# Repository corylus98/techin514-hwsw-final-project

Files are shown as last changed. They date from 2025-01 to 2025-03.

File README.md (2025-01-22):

# Final Project - Hardware/Software Lab

## Focus Track
The product is a desktop companion device designed to enhance productivity and well-being while working. It sits beside the user's computer and uses sensors to monitor typing patterns and screen time. By analyzing typing speed and consistency, it identifies whether the user is focused on productive tasks or engaging in non-work-related activities. The device features:
- Focus Level Indicator: A needle-style display that reflects the user's focus level based on typing behavior, encouraging sustained productivity.
- Break Reminder System: An LED light that gently alerts the user when they've been at their screen for too long, promoting healthier work habits through regular breaks.

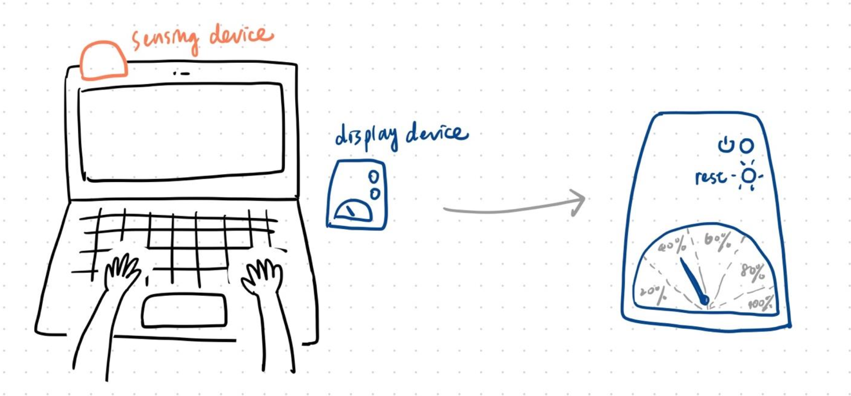
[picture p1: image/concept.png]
Imgae showing the scenario and concept of the idea.


## Sensor Device
The sensor device combines a vibration sensor and a proximity sensor to enable analysis of focus and screen usage.
- The vibration sensor detects typing actions, analyzing patterns to determine whether the user is typing productively.
- The proximity sensor tracks the user's presence in front of the screen to monitor screen time.

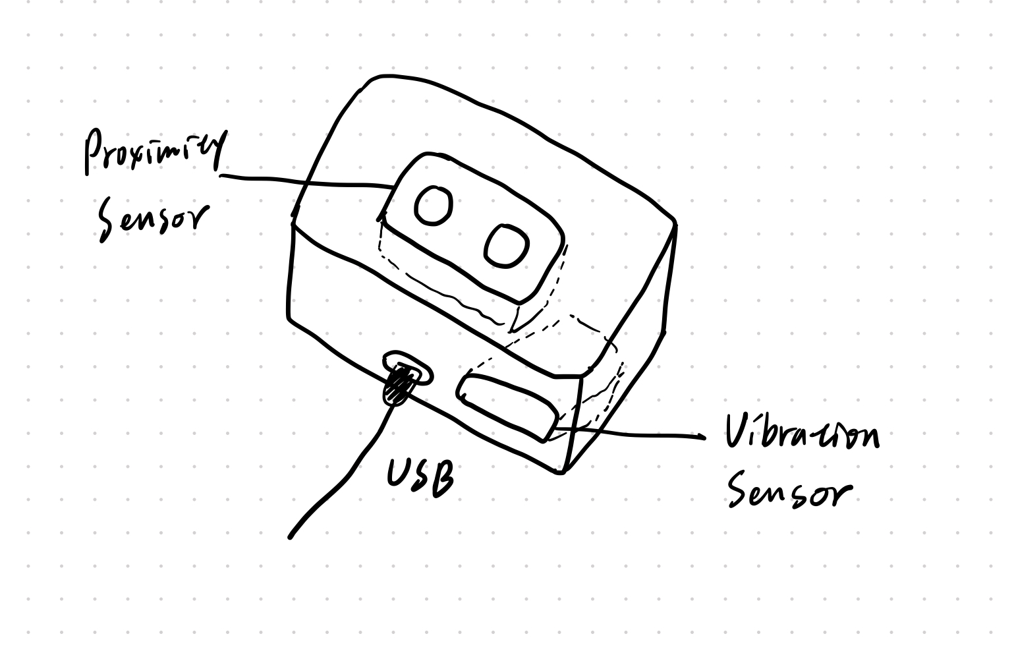
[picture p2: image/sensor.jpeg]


## Display Device
The display device interacts with the user through physical interfaces.
- The button allows the user to turn the device on or off.
- The needle indicator displays productivity levels, calculated based on typing patterns.
- The blinking LED light serves as a reminder to take breaks when screen time becomes excessive.

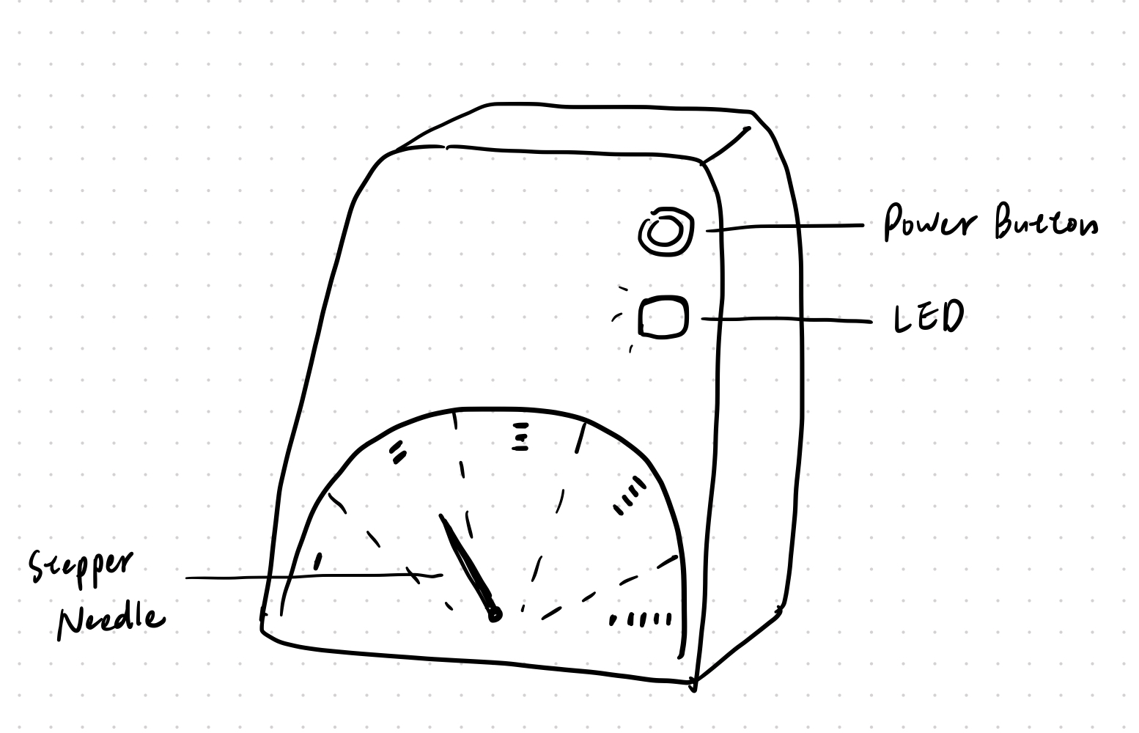
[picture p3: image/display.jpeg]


## Communication

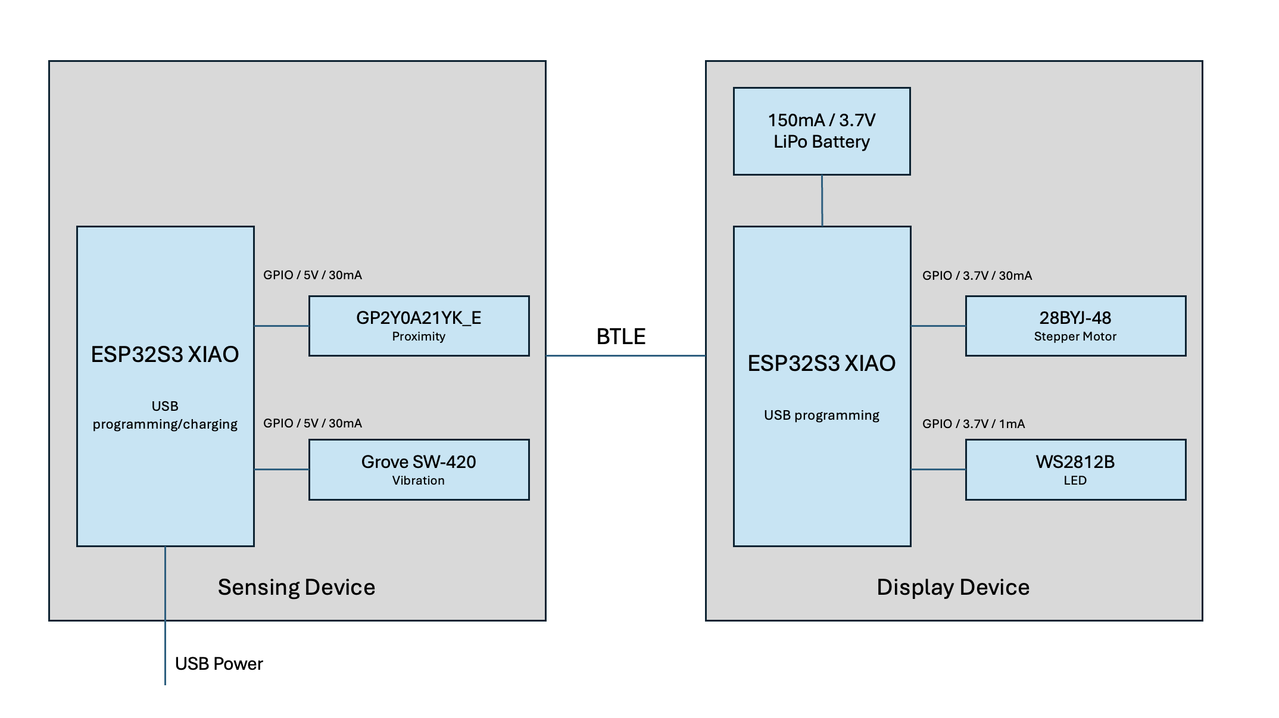
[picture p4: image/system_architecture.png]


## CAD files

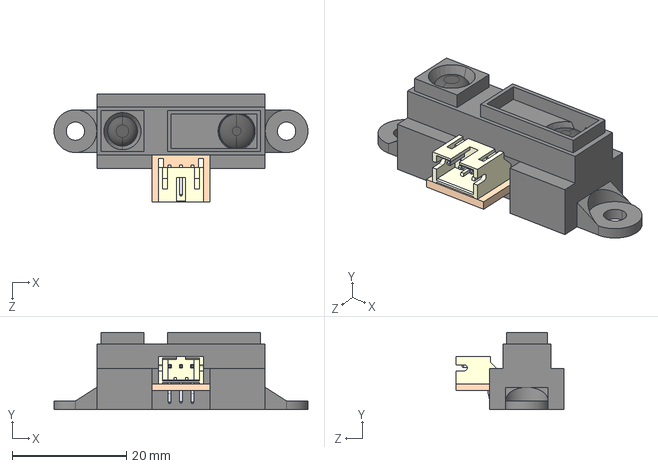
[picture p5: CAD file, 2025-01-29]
CAD_library/KiCad_GP2Y0A21YK0F/GP2Y0A21YK0F.step
44.5 x 13.5 x 18.9 mm

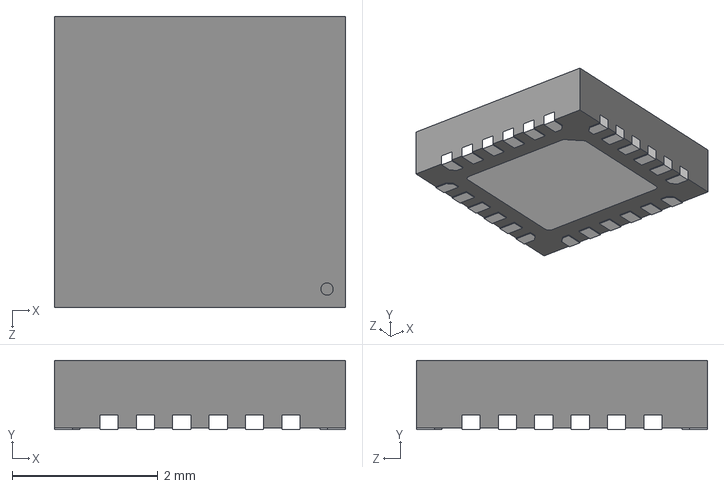
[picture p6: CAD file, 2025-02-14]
CAD_library/MPU-6050/MPU-6050.step
4.00 x 0.95 x 4.00 mm

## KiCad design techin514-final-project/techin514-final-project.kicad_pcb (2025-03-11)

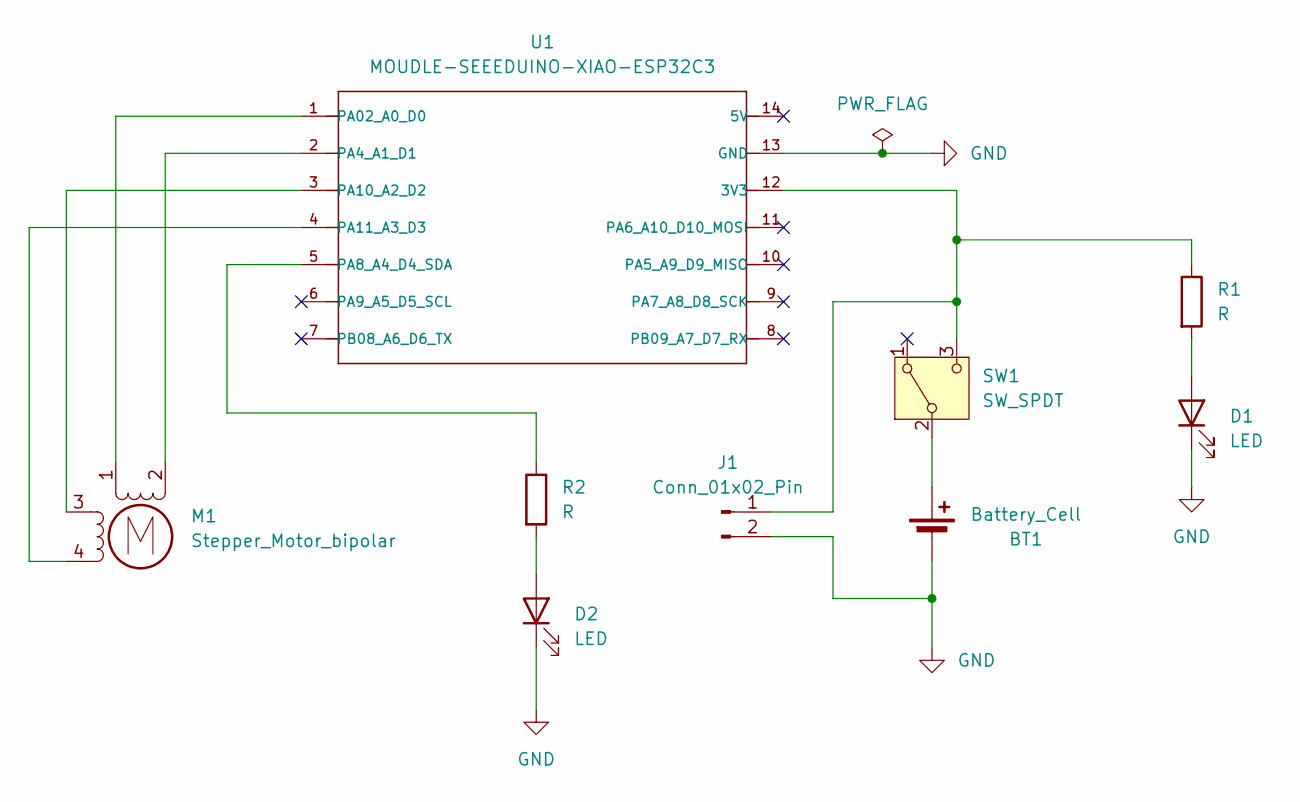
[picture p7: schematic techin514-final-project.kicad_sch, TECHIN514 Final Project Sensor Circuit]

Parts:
BT1: Battery_Cell; JST_PH_B2B-PH-K_1x02_P2.00mm_Vertical
D1, D2: LED; LED_D5.0mm
J1: Conn_01x02_Pin; JST_PH_B2B-PH-K_1x02_P2.00mm_Vertical
M1: Stepper_Motor_bipolar; x27_stepper_two_holes
R1, R2: R; R_Axial_DIN0207_L6.3mm_D2.5mm_P15.24mm_Horizontal
SW1: SW_SPDT; JST_EH_B3B-EH-A_1x03_P2.50mm_Vertical
U1: MOUDLE-SEEEDUINO-XIAO-ESP32C3; XIAO_ESP32_SENSE

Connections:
GND: BT1.2 (-), D1.1 (K), D2.1 (K), J1.2, U1.13 (GND)
unnamed: BT1.1 (+), SW1.2 (B)
unnamed: D1.2 (A), R1.2
unnamed: D2.2 (A), R2.2
unnamed: J1.1, R1.1, SW1.3 (C), U1.12 (3V3)
unnamed: M1.2 (-), U1.2 (PA4_A1_D1)
unnamed: M1.1, U1.1 (PA02_A0_D0)
unnamed: R2.1, U1.5 (PA8_A4_D4_SDA)
unnamed: M1.3, U1.3 (PA10_A2_D2)
unnamed: M1.4, U1.4 (PA11_A3_D3)

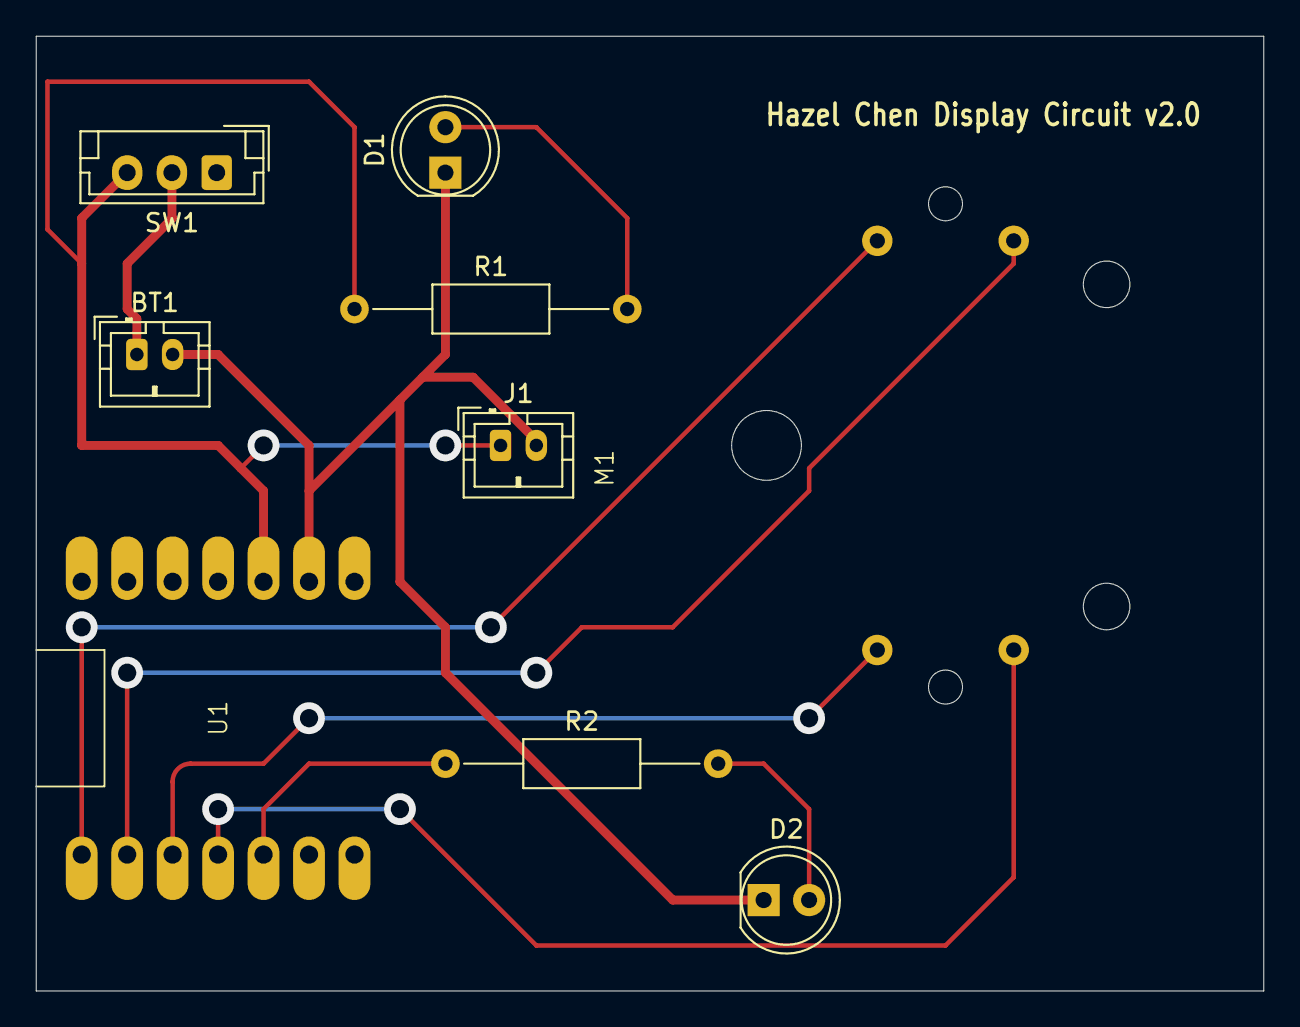
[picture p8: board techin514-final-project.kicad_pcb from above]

Board: 2 copper layers, 68.6 x 53.3 mm, 9 parts (0 on the bottom side), 10 nets.

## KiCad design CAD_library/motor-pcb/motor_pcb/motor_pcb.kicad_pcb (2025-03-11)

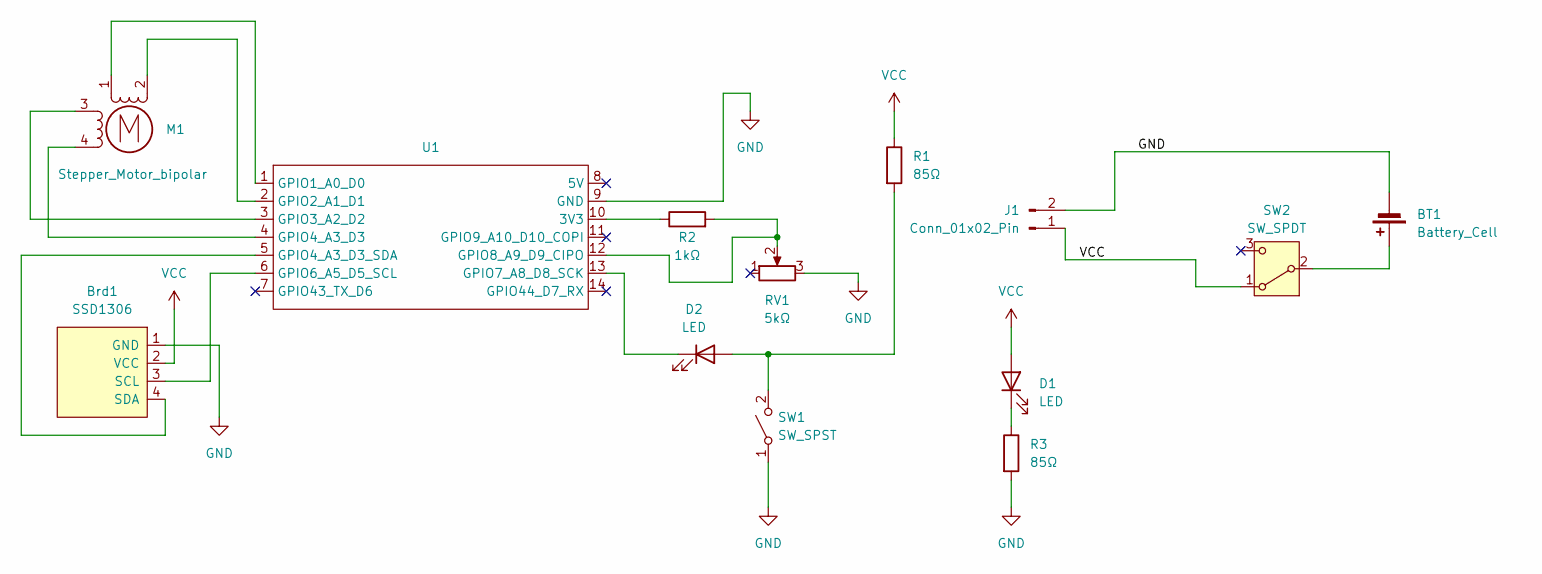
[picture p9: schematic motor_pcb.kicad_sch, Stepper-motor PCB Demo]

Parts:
BT1: Battery_Cell; JST_NV_B02P-NV_1x02_P5.00mm_Vertical
Brd1: SSD1306; 128x64OLED
D1, D2: LED; LED_0805_2012Metric_Pad1.15x1.40mm_HandSolder
J1: Conn_01x02_Pin; JST_NV_B02P-NV_1x02_P5.00mm_Vertical
M1: Stepper_Motor_bipolar; x27_stepper
R1, R3: 85Ω; R_0805_2012Metric_Pad1.20x1.40mm_HandSolder
R2: 1kΩ; R_0805_2012Metric_Pad1.20x1.40mm_HandSolder
RV1: 5kΩ; Potentiometer_Piher_T-16H_Single_Horizontal
SW1: SW_SPST; SW_PUSH-12mm
SW2: SW_SPDT; PinHeader_1x03_P2.54mm_Vertical
U1: XIAO_ESP32_SENSE

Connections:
GND: BT1.2 (-), Brd1.1 (GND), J1.2, R3.2, RV1.3, SW1.1 (A), U1.9 (GND)
unnamed: BT1.1 (+), SW2.2 (B)
unnamed: Brd1.3 (SCL), U1.6 (GPIO6_A5_D5_SCL)
unnamed: Brd1.4 (SDA), U1.5 (GPIO4_A3_D3_SDA)
unnamed: D1.1 (K), R3.1
unnamed: D2.2 (A), R1.2, SW1.2 (B)
unnamed: D2.1 (K), U1.13 (GPIO7_A8_D8_SCK)
unnamed: M1.2 (-), U1.2 (GPIO2_A1_D1)
unnamed: R2.1, U1.10 (3V3)
unnamed: M1.1, U1.1 (GPIO1_A0_D0)
unnamed: M1.3, U1.3 (GPIO3_A2_D2)
unnamed: M1.4, U1.4 (GPIO4_A3_D3)
unnamed: R2.2, RV1.2, U1.12 (GPIO8_A9_D9_CIPO)
VCC: Brd1.2 (VCC), D1.2 (A), J1.1, R1.1, SW2.1 (A)

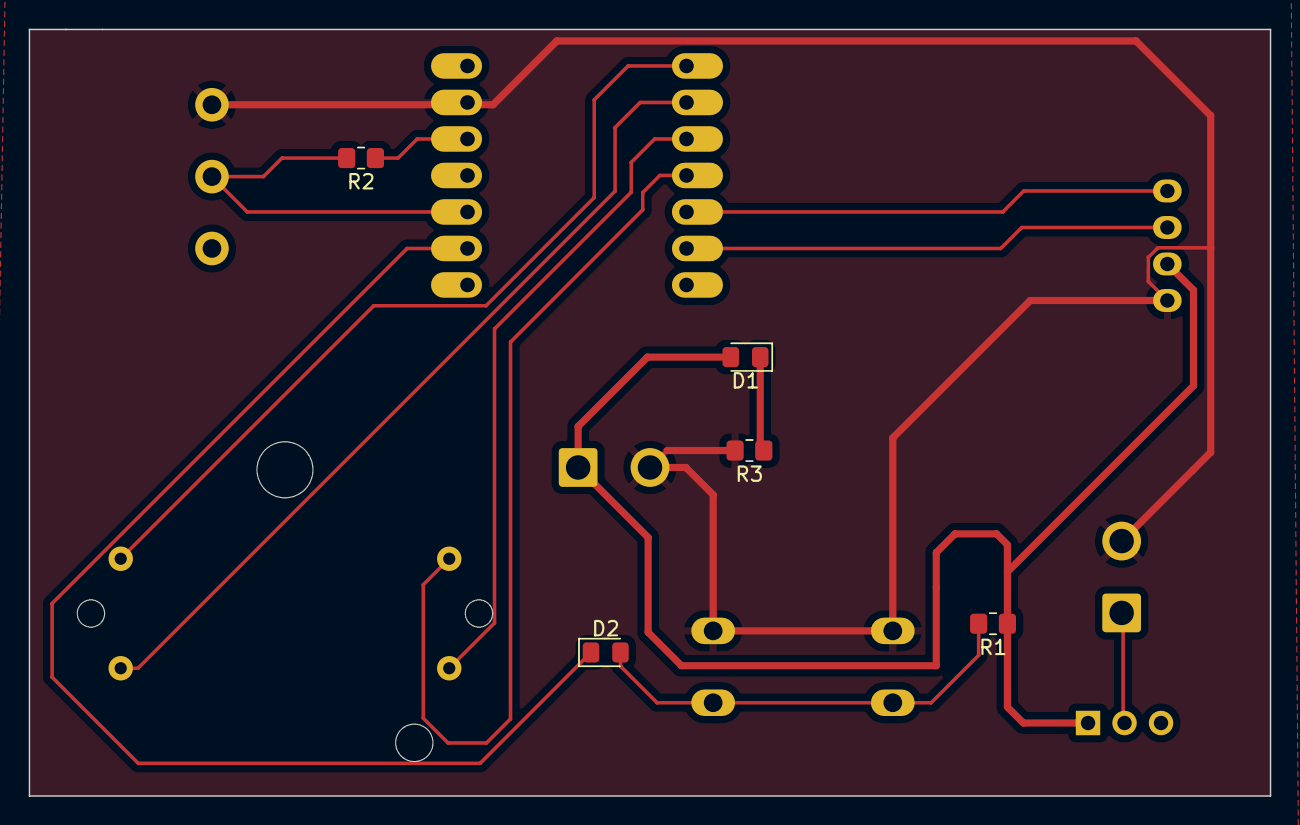
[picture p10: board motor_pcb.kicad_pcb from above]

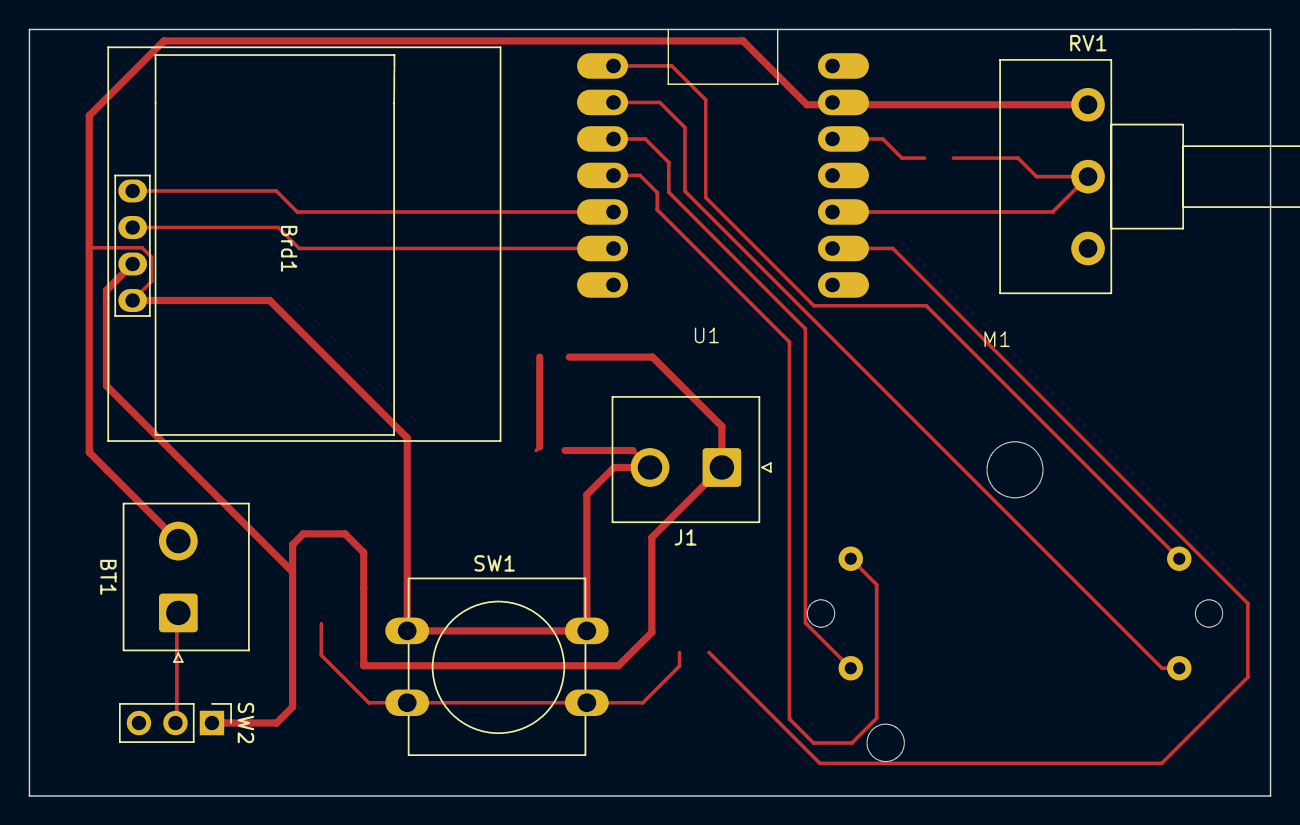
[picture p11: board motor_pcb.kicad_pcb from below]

Board: 2 copper layers, 86.4 x 53.3 mm, 13 parts (8 on the bottom side), 14 nets.

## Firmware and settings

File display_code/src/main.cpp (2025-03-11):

#include <Arduino.h>
#include <BLEDevice.h>
#include <BLEUtils.h>
#include <BLEScan.h>
#include <BLEAdvertisedDevice.h>
#include <AccelStepper.h>

#define MOTOR_PIN_1 5
#define MOTOR_PIN_2 6
#define LED_PIN 3

#define STEP_20_DEGREES 60  // Steps required to rotate 90 degrees
#define STEP_180_DEGREES 540 // Steps required to rotate 180 degrees
#define ORIGIN 0

AccelStepper stepper(AccelStepper::FULL2WIRE, MOTOR_PIN_1, MOTOR_PIN_2);
bool hasMoved180 = false;

static BLEUUID serviceUUID("04faf1c3-e3d5-49c0-9ead-e628bc35a133");
static BLEUUID charUUID("90705d32-c022-4a47-bda4-8ff642549198");

static BLERemoteCharacteristic* pRemoteCharacteristic;
static BLEAdvertisedDevice* myDevice;
static boolean connected = false;
static boolean doConnect = false;
static boolean doScan = false;

// BLE Scanning
class MyAdvertisedDeviceCallbacks: public BLEAdvertisedDeviceCallbacks {
  void onResult(BLEAdvertisedDevice advertisedDevice) {
    if (advertisedDevice.haveServiceUUID() && advertisedDevice.isAdvertisingService(serviceUUID)) {
      BLEDevice::getScan()->stop();
      myDevice = new BLEAdvertisedDevice(advertisedDevice);
      doConnect = true;
      doScan = true;
    }
  }
};

// Distance tracking
unsigned long distanceStartTime = 0;
bool isTrackingDistance = false;

// Function to blink LED
void blinkLED(int duration) {
    Serial.println("LED");
    digitalWrite(LED_PIN, HIGH);
    delay(duration);
    digitalWrite(LED_PIN, LOW);
}

// Function to move the stepper motor
void moveStepper(int targetPosition) {
    Serial.print("Moving stepper to position: ");
    Serial.println(targetPosition);

    stepper.moveTo(targetPosition);
    while (stepper.distanceToGo() != 0) {
        stepper.run();
    }

    // Check if motor reached 180 degrees
    if (targetPosition == STEP_180_DEGREES) {
        hasMoved180 = true;
    }
}

// BLE Data Processing
void processBLEData(String data) {
    Serial.print("Received BLE Data: ");
    Serial.println(data);

    // Check for frequency match signal
    if (data == "FREQ_MATCH") {
        moveStepper(STEP_20_DEGREES);
        Serial.println("Peak frequency detected. Moving stepper motor.");
    }

    // Check for proximity alert signal
    if (data == "PROXIMITY_ALERT") {
        blinkLED(5000);
        Serial.println("Proximity alert received. Blinking LED for 5 seconds.");
    }
}

// BLE Notification Callback
static void notifyCallback(
  BLERemoteCharacteristic* pBLERemoteCharacteristic,
  uint8_t* pData,
  size_t length,
  bool isNotify) {
    String receivedString = String((char*)pData).substring(0, length);
    Serial.print("Raw BLE Data: ");
    Serial.println(receivedString);
    
    processBLEData(receivedString);
}

// BLE Connection Callback
std::string serverDeviceName = ""; 
class MyClientCallback : public BLEClientCallbacks {
  void onConnect(BLEClient* pclient) {
    serverDeviceName = myDevice->getName();
    Serial.println("✅ Connected to BLE Server.");
    Serial.println(serverDeviceName.c_str());
  }
  void onDisconnect(BLEClient* pclient) {
    connected = false;
    Serial.println("❌ Disconnected from BLE Server.");
  }
};

// Connect to BLE Server
bool connectToServer() {
  Serial.print("Connecting to ");
  Serial.println(myDevice->getAddress().toString().c_str());

  BLEClient* pClient = BLEDevice::createClient();
  pClient->setClientCallbacks(new MyClientCallback());

  pClient->connect(myDevice);
  Serial.println("Connected to BLE server.");
  pClient->setMTU(517);

  BLERemoteService* pRemoteService = pClient->getService(serviceUUID);
  if (pRemoteService == nullptr) {
    Serial.println("Failed to find service UUID.");
    pClient->disconnect();
    return false;
  }

  serverDeviceName = myDevice->getName();

  pRemoteCharacteristic = pRemoteService->getCharacteristic(charUUID);
  if (pRemoteCharacteristic == nullptr) {
    Serial.println("Failed to find characteristic UUID.");
    pClient->disconnect();
    return false;
  }

  if(pRemoteCharacteristic->canRead()) {
    std::string value = pRemoteCharacteristic->readValue();
    Serial.print("The characteristic value was: ");
    Serial.println(value.c_str());
  }

  if (pRemoteCharacteristic->canNotify()) {
    pRemoteCharacteristic->registerForNotify(notifyCallback);
  }

  connected = true;
  return true;
}

void setup() {
  Serial.begin(115200);
  Serial.println("Starting BLE Display Controller...");

  BLEDevice::init("");

  BLEScan* pBLEScan = BLEDevice::getScan();
  pBLEScan->setAdvertisedDeviceCallbacks(new MyAdvertisedDeviceCallbacks());
  pBLEScan->setInterval(1349);
  pBLEScan->setWindow(449);
  pBLEScan->setActiveScan(true);
  pBLEScan->start(5, false);

  stepper.setMaxSpeed(500);
  stepper.setAcceleration(300);

  // Initialize LED pin
  pinMode (LED_PIN, OUTPUT);

  stepper.setCurrentPosition(ORIGIN);
  Serial.println("Stepper initialized at origin.");
}

void loop() {
  if (doConnect) {
    if (connectToServer()) {
      Serial.println("Connected to BLE Server.");
    } else {
      Serial.println("Failed to connect.");
    }
    doConnect = false;
  }

  if (connected) {
    String newValue = "Time since boot: " + String(millis()/1000);
    Serial.println("Setting new characteristic value to \"" + newValue  + "\"");
    pRemoteCharacteristic->writeValue(newValue.c_str(), newValue.length());
  } else if (doScan) {
    BLEDevice::getScan()->start(0);
  }

  if (hasMoved180) {
      Serial.println("Stepper moved 180 degrees. Returning to origin...");
      moveStepper(ORIGIN);
      hasMoved180 = false;
  }

  delay(1000);
}

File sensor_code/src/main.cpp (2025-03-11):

#include <Arduino.h>
#include <Wire.h>
#include <driver/i2s.h>
#include "arduinoFFT.h" 
#include <U8g2lib.h>
#include <BLEDevice.h>
#include <BLEServer.h>
#include <BLEUtils.h>
#include <BLE2902.h>
#include <stdlib.h>

BLEServer* pServer = NULL;
BLECharacteristic* pCharacteristic = NULL;
bool deviceConnected = false;
bool oldDeviceConnected = false;
unsigned long previousMillis = 0;
const long interval = 1000;
unsigned long lastTimeBelowThreshold = 0;
bool trackingProximity = false;

#define I2S_WS   9  // LRCLK (Word Select)
#define I2S_DIN  8  // Data In (DOUT from mic)
#define I2S_BCLK 20  // Bit Clock
#define TIME_THRESHOLD 120000
#define TARGET_FREQUENCY 62.5
#define DISTANCE_THRESHOLD 100
const int trigPin = 2;
const int echoPin = 3;

#define SCL_INDEX 0x00
#define SCL_TIME 0x01
#define SCL_FREQUENCY 0x02                                 
#define SCL_PLOT 0x03                                                       
                                                     
#define BUFFER_SIZE 512  // Buffer for storing audio samples

#define SAMPLES 512  // Number of samples for FFT, must be a power of 2
#define SAMPLING_FREQUENCY 16000  // Adjust based on your microphone's sampling rate

double vReal[SAMPLES];  // Array to store the real part of the FFT (audio data)
double vImag[SAMPLES];  // Array to store the imaginary part (set to 0)
float duration, distance;

ArduinoFFT<double> FFT = ArduinoFFT<double>(vReal, vImag, SAMPLES, SAMPLING_FREQUENCY);
double FindPeakFrequency(double* fftData, int numSamples);
U8G2_SSD1306_128X64_NONAME_F_SW_I2C u8g2(U8G2_R0, /* clock=*/ 7, /* data=*/ 6, /* reset=*/ U8X8_PIN_NONE);

#define SERVICE_UUID        "04faf1c3-e3d5-49c0-9ead-e628bc35a133"
#define CHARACTERISTIC_UUID "90705d32-c022-4a47-bda4-8ff642549198"

class MyServerCallbacks : public BLEServerCallbacks {
    void onConnect(BLEServer* pServer) {
        deviceConnected = true;
        Serial.println("✅ BLE Device Connected");
    };
 
    void onDisconnect(BLEServer* pServer) {
        deviceConnected = false;
        Serial.println("❌ BLE Device Disconnected");
    }
};

void setup() {

    Serial.begin(115200);
    pinMode(trigPin, OUTPUT);                 
    pinMode(echoPin, INPUT);                                                        
    Wire.begin(); 
    u8g2.begin();
    u8g2.setFlipMode(1);

    // Configure I2S          
    i2s_config_t i2s_config = {
        .mode = (i2s_mode_t)(I2S_MODE_MASTER | I2S_MODE_RX),
        .sample_rate = 16000,
        .bits_per_sample = I2S_BITS_PER_SAMPLE_16BIT,
        .channel_format = I2S_CHANNEL_FMT_ONLY_LEFT, // Using left channel
        .communication_format = I2S_COMM_FORMAT_I2S,
        .intr_alloc_flags = 0,
        .dma_buf_count = 8,
        .dma_buf_len = 512
    };

    i2s_pin_config_t pin_config = {
        .bck_io_num = I2S_BCLK,
        .ws_io_num = I2S_WS,
        .data_out_num = I2S_PIN_NO_CHANGE,
        .data_in_num = I2S_DIN
    };

    i2s_driver_install(I2S_NUM_0, &i2s_config, 0, NULL);
    i2s_set_pin(I2S_NUM_0, &pin_config);

    // // Name server device
    // BLEDevice::init("SWHW_Sensor🌲🌲🌲");
    // pServer = BLEDevice::createServer();
    // pServer->setCallbacks(new MyServerCallbacks());
    // BLEService *pService = pServer->createService(SERVICE_UUID);
    // pCharacteristic = pService->createCharacteristic(
    //     CHARACTERISTIC_UUID,
    //     BLECharacteristic::PROPERTY_READ |
    //     BLECharacteristic::PROPERTY_WRITE |
    //     BLECharacteristic::PROPERTY_NOTIFY
    // );
    // pCharacteristic->addDescriptor(new BLE2902());
    // pCharacteristic->setValue("👋 Hello World 👋");
    // pService->start();
    // // BLEAdvertising *pAdvertising = pServer->getAdvertising();  // this is working for backward compatibility
    // BLEAdvertising *pAdvertising = BLEDevice::getAdvertising();
    // pAdvertising->addServiceUUID(SERVICE_UUID);
    // pAdvertising->setScanResponse(true);
    // pAdvertising->setMinPreferred(0x06);  // functions that help with iPhone connections issue
    // pAdvertising->setMinPreferred(0x12);
    // BLEDevice::startAdvertising();  
}


void loop() {
    int16_t sampleBuffer[SAMPLES];  // Array to store raw audio samples
    size_t bytesRead;

    // Read I2S audio data
    i2s_read(I2S_NUM_0, sampleBuffer, sizeof(sampleBuffer), &bytesRead, portMAX_DELAY);

    // Convert the raw 16-bit samples to double values for FFT processing
    for (int i = 0; i < SAMPLES; i++) {
        vReal[i] = (double)sampleBuffer[i];  // Assign real part
        vImag[i] = 0.0;  // Imaginary part is zeroed
    }
                                        
    // Perform FFT
    FFT.windowing(FFTWindow::Hamming, FFTDirection::Forward);  // Apply Hamming window
    FFT.compute(FFTDirection::Forward);  // Compute FFT
    FFT.complexToMagnitude();  // Convert to magnitudes
                
    // Get the major peak frequency
    double peakFreq = FindPeakFrequency(vReal, SAMPLES);

    Serial.print("Major peak frequency: ");
    Serial.print(peakFreq);
    Serial.println(" Hz");

    digitalWrite(trigPin, LOW);
    delayMicroseconds(2);
    digitalWrite(trigPin, HIGH);
    delayMicroseconds(10);
    digitalWrite(trigPin, LOW);

    duration = pulseIn(echoPin, HIGH);
    distance = (duration*.0343)/2;
    Serial.print("Distance: ");
    Serial.println(distance);

    u8g2.clearBuffer();
    u8g2.setFont(u8g2_font_ncenB08_tr);                  

    // Display Peak Frequency
    u8g2.setCursor(10, 20);
    if (peakFreq == 62.5) {
      u8g2.print("Typing...");
    }
    // u8g2.print("Freq: ");
    // u8g2.print(peakFreq);
    // u8g2.print(" Hz");

    // Display Distance
    u8g2.setCursor(10, 40);
    if (distance < 100) {
      u8g2.print("At screen");
    } else {
      u8g2.print("Off screen");
    }
    // u8g2.print("Dist: ");
    // u8g2.print(distance);
    // u8g2.print(" cm");

    u8g2.sendBuffer();

    unsigned long currentMillis = millis();
  // previousMillis = currentMillis;

    if (deviceConnected) {
        // Send new readings to database
        if (peakFreq == TARGET_FREQUENCY) {
        pCharacteristic->setValue("FREQ_MATCH");
        pCharacteristic->notify();
        Serial.println("🎙️ Send Frequency 🎙️");
        }   
        if (distance < DISTANCE_THRESHOLD) {
        if (!trackingProximity) {
            trackingProximity = true;
            lastTimeBelowThreshold = currentMillis;
        } else if (currentMillis - lastTimeBelowThreshold >= TIME_THRESHOLD) {
            pCharacteristic->setValue("PROXIMITY_ALERT");
            pCharacteristic->notify();
            trackingProximity = false;
            Serial.println("🎯 Send Proximity 🎯");
        }
        } else {
        trackingProximity = false;
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

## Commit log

2025-01-29 Add KiCAD files
    [GP2Y0A21YK0F.step, techin514-final-project.kicad_pcb, techin514-final-project.kicad_sch]
2025-01-29 Modify CAD files
    [GP2Y0A21YK0F.step, techin514-final-project.kicad_pcb, techin514-final-project.kicad_sch]
2025-02-14 Add Battery Datasheet
    [MPU-6050.step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]
2025-03-11 Add sensor code
    [motor_pcb-B_Cu.gbr, motor_pcb-B_Mask.gbr, motor_pcb-B_Paste.gbr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]
